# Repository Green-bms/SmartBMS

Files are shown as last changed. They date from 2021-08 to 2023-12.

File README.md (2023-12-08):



# SmartBMS
Open source Smart Battery Management System

Youtube presentation:
https://youtu.be/0XNe25lMs6U?si=eK-90N3kao_sy4zy

Official page:
https://hackaday.io/project/181453-green-bms

## Description
Smart BMS is an Open Source Battery Management System for Lithium Cells (Lifepo4, Li-ion, NCM, etc.) Battery Pack.



The main functions of BMS are:
- To protect cells against overvoltage
- To protect cells against undervoltage
- To balance the cells 

Smart BMS consists of four main components:
1. Cell Module (https://hackaday.io/project/181453-green-bms/log/198376-green-bms-cell-module)
2. Control Unit (https://hackaday.io/project/181453-green-bms/log/198414-green-bms-control-unit)
3. Limiter (https://hackaday.io/project/181453-green-bms/log/198378-green-bms-limiter)
4. Android App (https://hackaday.io/project/181453-green-bms/log/198377-green-bms-android-app)

The voltage and the temperature values of each cell are acquired by the relevant Cell Module (based on Attiny microcontroller) and sent to Control Unit (based on Arduino Mega microcontroller) through a serial I2C line.

Control Unit starts or stop charging (by output relay) through Limiter, that includes a power relay for opening or closing the charging circuit.

Control Unit can also start or stop discharging by output relay.

When during charging a cell reaches the “Balance voltage value parameter”, the Cell Module connects the balance resistors in order to perform the cell bleeding.

When just one cell of the pack is balancing, Control Unit activates the current limit function inside the Limiter (the charging current is limited to 1A).

Control Unit can be connected with a Smartphone (or a Tablet) by Bluetooth.

By “Green BMS” Android app (available on Play Store) it is possible to check the Battery Pack status (total voltage, current load, state of charge…) , to check the actual voltage and temperature values of each cell and to perform several settings.

## Android App free download
The Green BMS Android app is available here: 
[Green-BMS App](https://play.google.com/store/apps/details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)

## Tutorials

Step by step instructions for make Green BMS are available here:
https://hackaday.io/project/181453/instructions

## Youtube channel

https://www.youtube.com/channel/UCdJnQnmzJSQNOAGbZR5iExA

Subscribe please... :smile:

## Open source Development applications

The project was created using the following Open source applications:
- **KiCad** : to design cell module and Interface board
- **QElectroTech** : to design Limiter
- **LibreCad 2D** : to desingn Control Unit Box
- **Arduino IDE** : to design the code of Cell Module(Attiny) and Control Unit(Arduino Mega)
- **Mit App Inventor** : to design the Android Application

## Warning

Lithium and other batteries are dangerous and must be treated with care.

Lithium and other batteries are potentially hazardous and can present a serious fire hazard if damaged, defective or improperly used.

Green BMS is a "do it yourself" project, with no warranties whatsoever.

Green BMS assumes no responsibility for any errors or inaccuracies that may appear in any documentation or file or any software that may be provided.

The use of this project is done entirely at your own risk and responsibility.

The use of this project may not be compliant with local laws or regulations.

## Open Source Hardware Certification

Green BMS has been certified as open source hardware by the Open Source Hardware Association, with the UID: IT000007.

Certificate link: (https://certification.oshwa.org/it000007.html)

## License

This work is licensed under a **Creative Commons Attribution-ShareAlike 4.0 International License**.
https://creativecommons.org/licenses/by-sa/4.0/

### You are free to:

**Share** — copy and redistribute the material in any medium or format

**Adapt**  — remix, transform, and build upon the material
for any purpose, even commercially.
This license is acceptable for Free Cultural Works.
The licensor cannot revoke these freedoms as long as you follow the license terms.

### Under the following terms:

**Attribution** — You must give appropriate credit, provide a link to the license, and indicate if changes were made. You may do so in any reasonable manner, but not in any way that suggests the licensor endorses you or your use.

**ShareAlike** — If you remix, transform, or build upon the material, you must distribute your contributions under the same license as the original.

**No additional restrictions** — You may not apply legal terms or technological measures that legally restrict others from doing anything the license permits.

### Notices:
You do not have to comply with the license for elements of the material in the public domain or where your use is permitted by an applicable exception or limitation.
No warranties are given. The license may not give you all of the permissions necessary for your intended use. For example, other rights such as publicity, privacy, or moral rights may limit how you use the material.

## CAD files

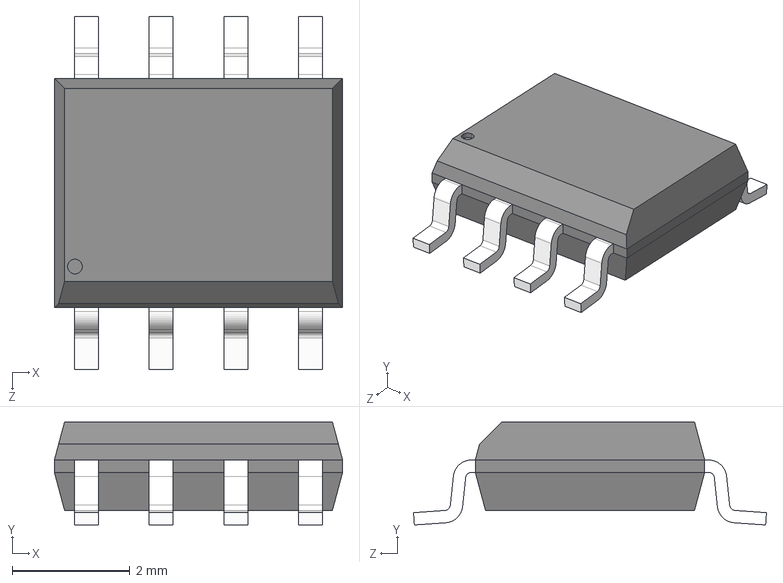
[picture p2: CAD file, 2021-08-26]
01_Documentation/Kikad additional libreries/Adum1250/ADUM1250.step
4.90 x 1.75 x 6.00 mm

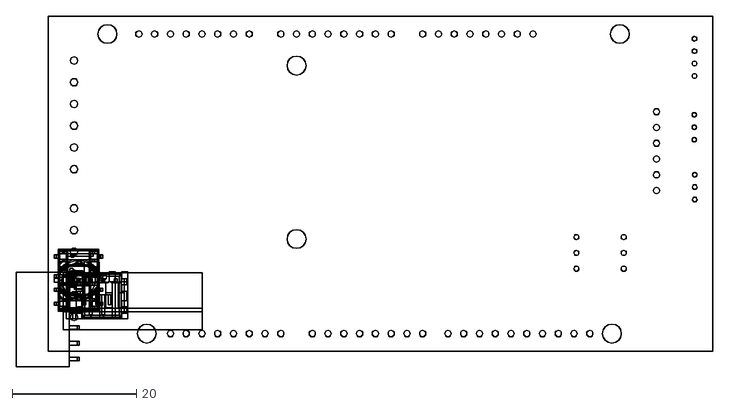
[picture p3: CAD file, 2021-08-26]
04_Interface board/Hardware/Kikad_Interface_board_1/Interface_board_1.dxf
112.2 x 56.5

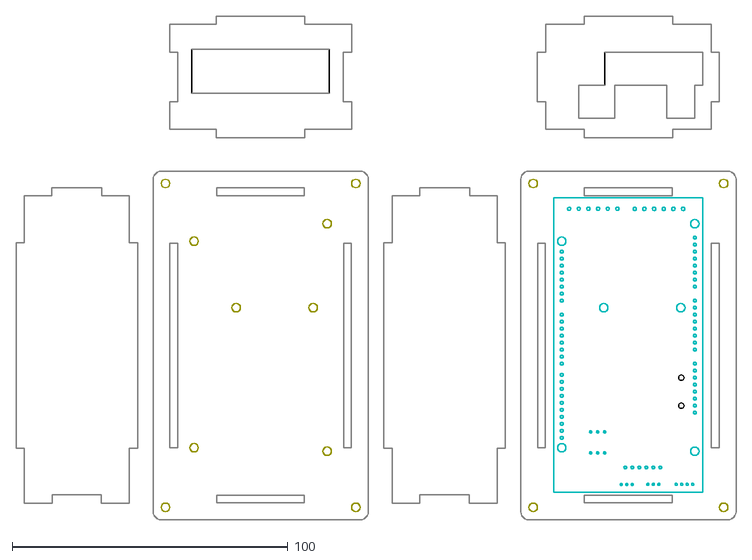
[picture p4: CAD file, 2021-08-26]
05_Control Unit case/Librecad_box_lcu_0_0/box_lcu_0_0.dxf
261.2 x 182.7

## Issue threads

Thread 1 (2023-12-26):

Implement taper current charging

idkq, 2023-12-26:
To implement taper current charging, the code would need to integrate real-time monitoring of the battery’s state of charge (SOC) and adjust the charging current accordingly as the SOC approaches 100%.

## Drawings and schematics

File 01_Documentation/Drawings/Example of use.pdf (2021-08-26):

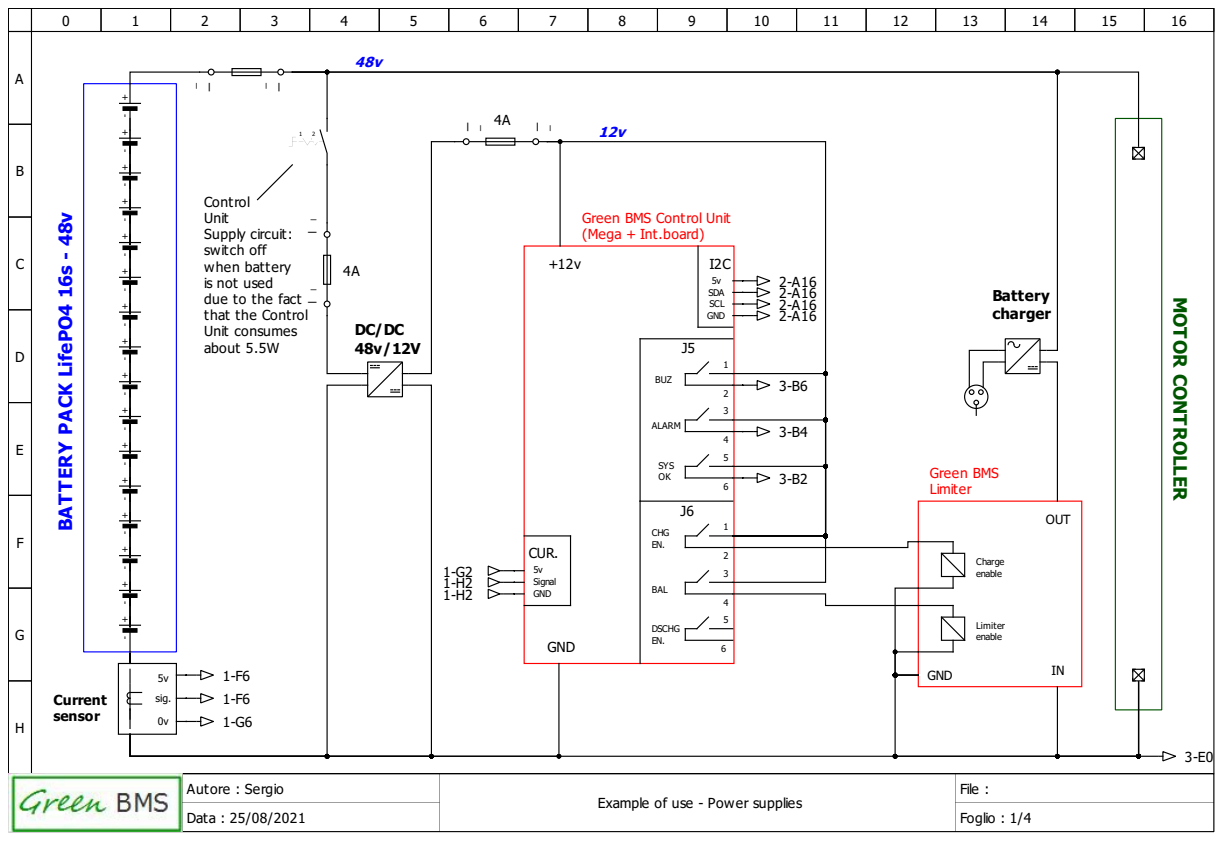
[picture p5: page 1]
ABCDEFGH; gio; ple; plie; File : Data : 25/08/2021; Foglio : 1; Limit; ble; 1 SDA5v SCL GND I2C J6 BAL CHG EN. CUR. Signal; Green BMS Control Unit (Mega + Int.board); 3253 GND 5v; BUZ J5 SYS OK DSCHG EN. ALARM; 4 GND; 0v sig. 5v ⁻ ⁺ ⁻ ⁺ ⁻ ⁺; MOTOR CONTROLLER; BATTERY PACK LifePO4 16s - 48v; ol Unit Supply; cir c

uit: switch off when battery is not used due to the fac

ol Unit consumes about 5.5W

16 | 15 | 14 | 13

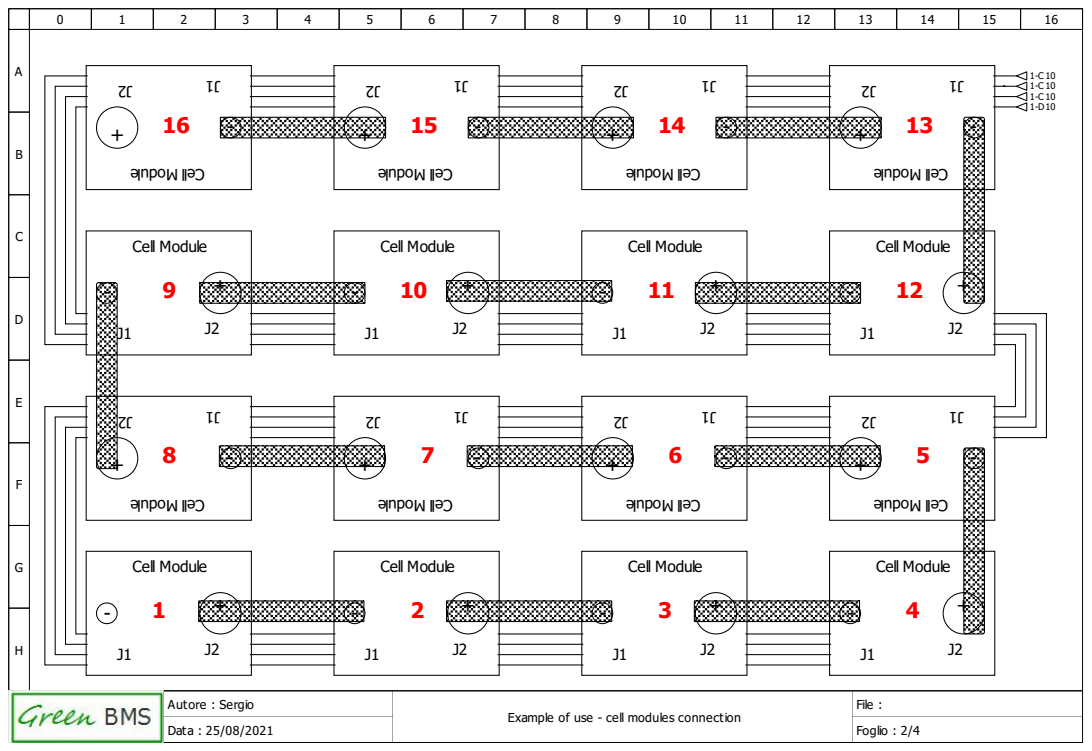
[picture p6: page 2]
Cell Module

Autore : Sergio | Example of use - cell modules connection | File :

Data : 25/08/2021 | | Foglio : 2/4

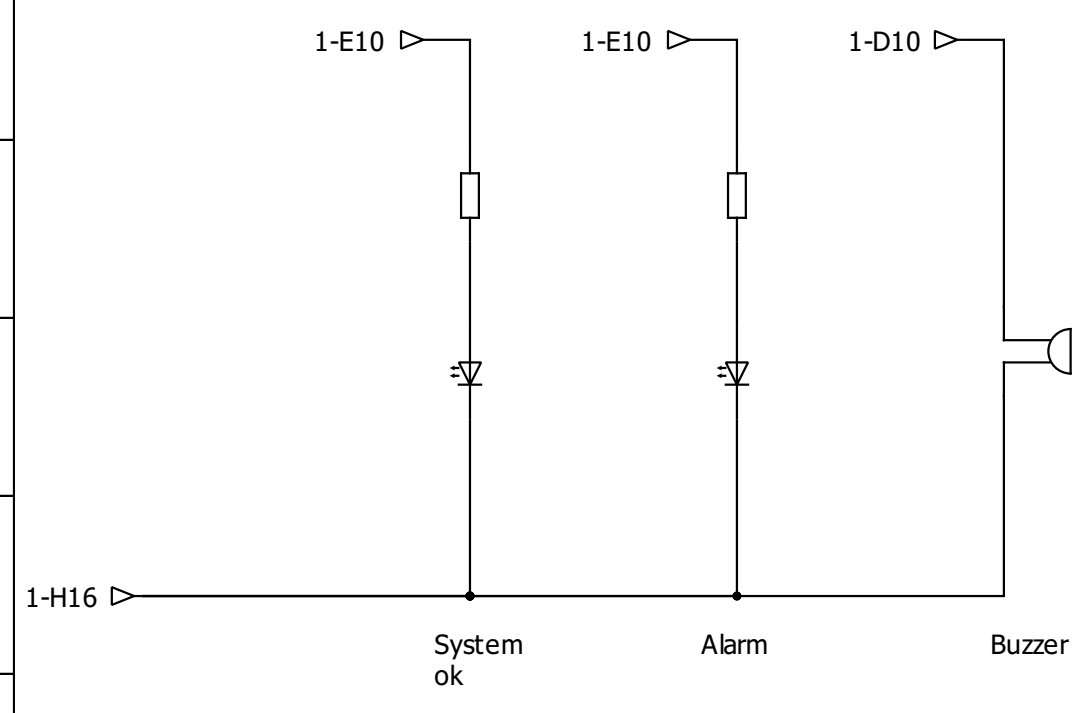
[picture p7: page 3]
Autore : Sergio; File :; System ok; Alarm; Buzzer

Example of use - indications

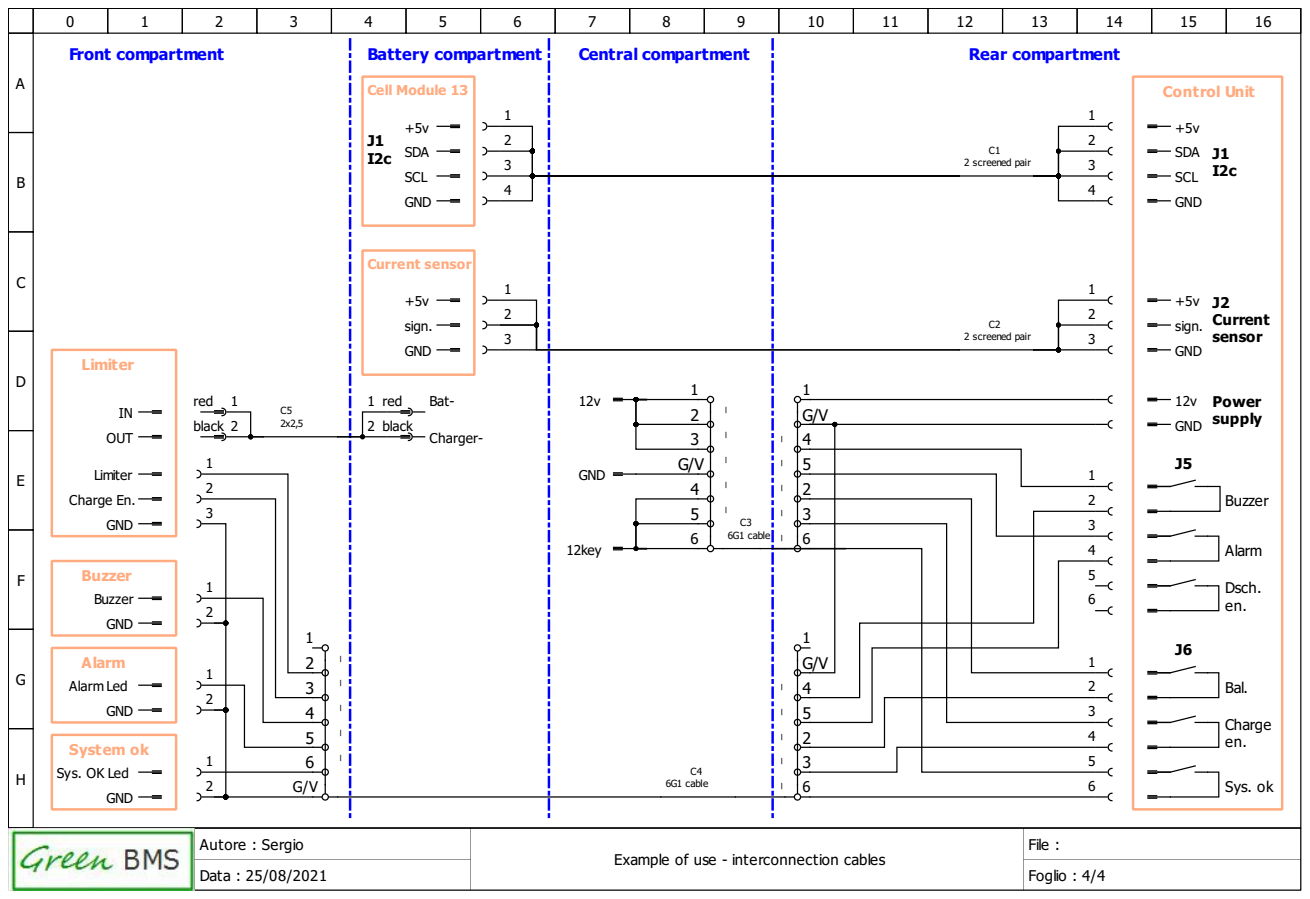
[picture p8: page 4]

Example of use - interconnection cables

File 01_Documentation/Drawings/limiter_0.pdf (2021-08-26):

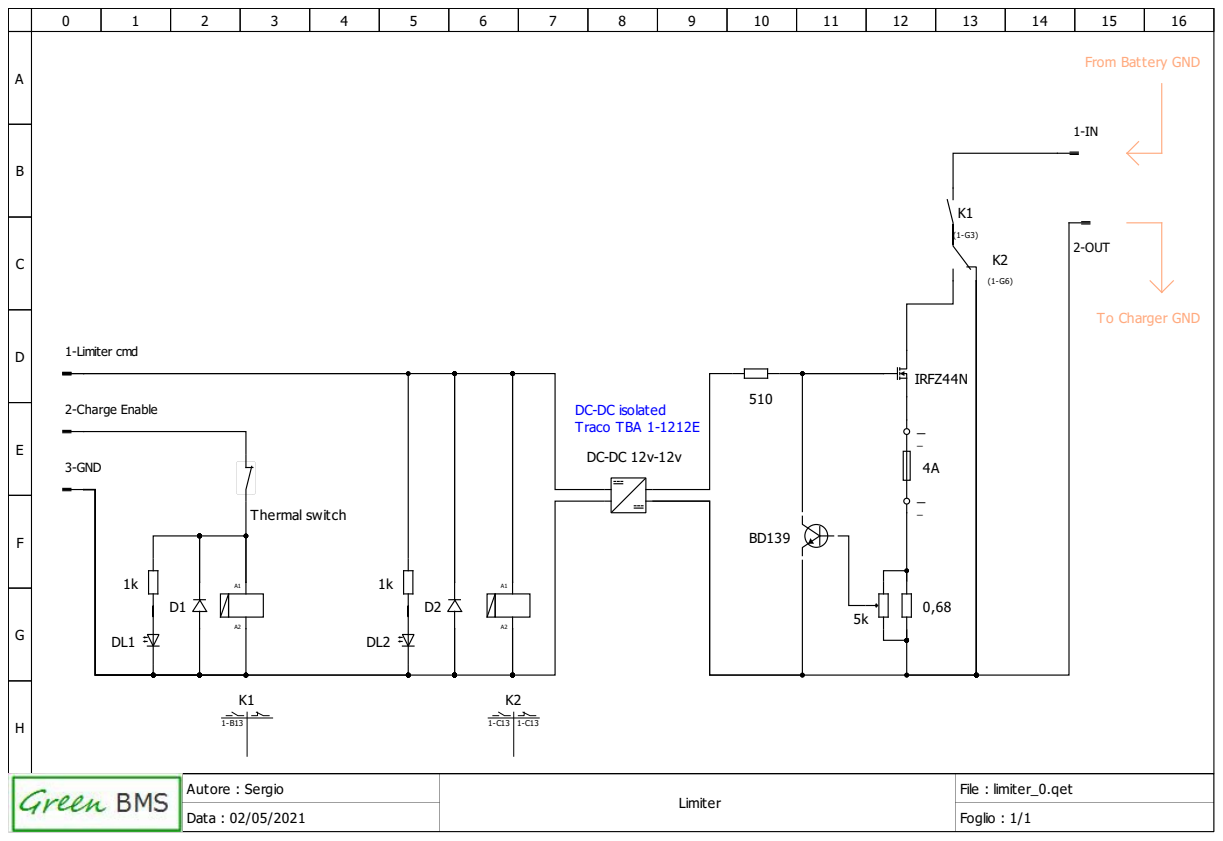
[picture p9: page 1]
1-Limiter cmd; IRFZ44N; Thermal switch; 3-GND; 2-Charge Enable; 2-OUT

From Battery GND

To Charger GND

DC-DC isolated
Traco TBA 1-1212E

Autore : Sergio | Limiter | File : limiter_0.qet

Data : 02/05/2021 | | Foglio : 1/1

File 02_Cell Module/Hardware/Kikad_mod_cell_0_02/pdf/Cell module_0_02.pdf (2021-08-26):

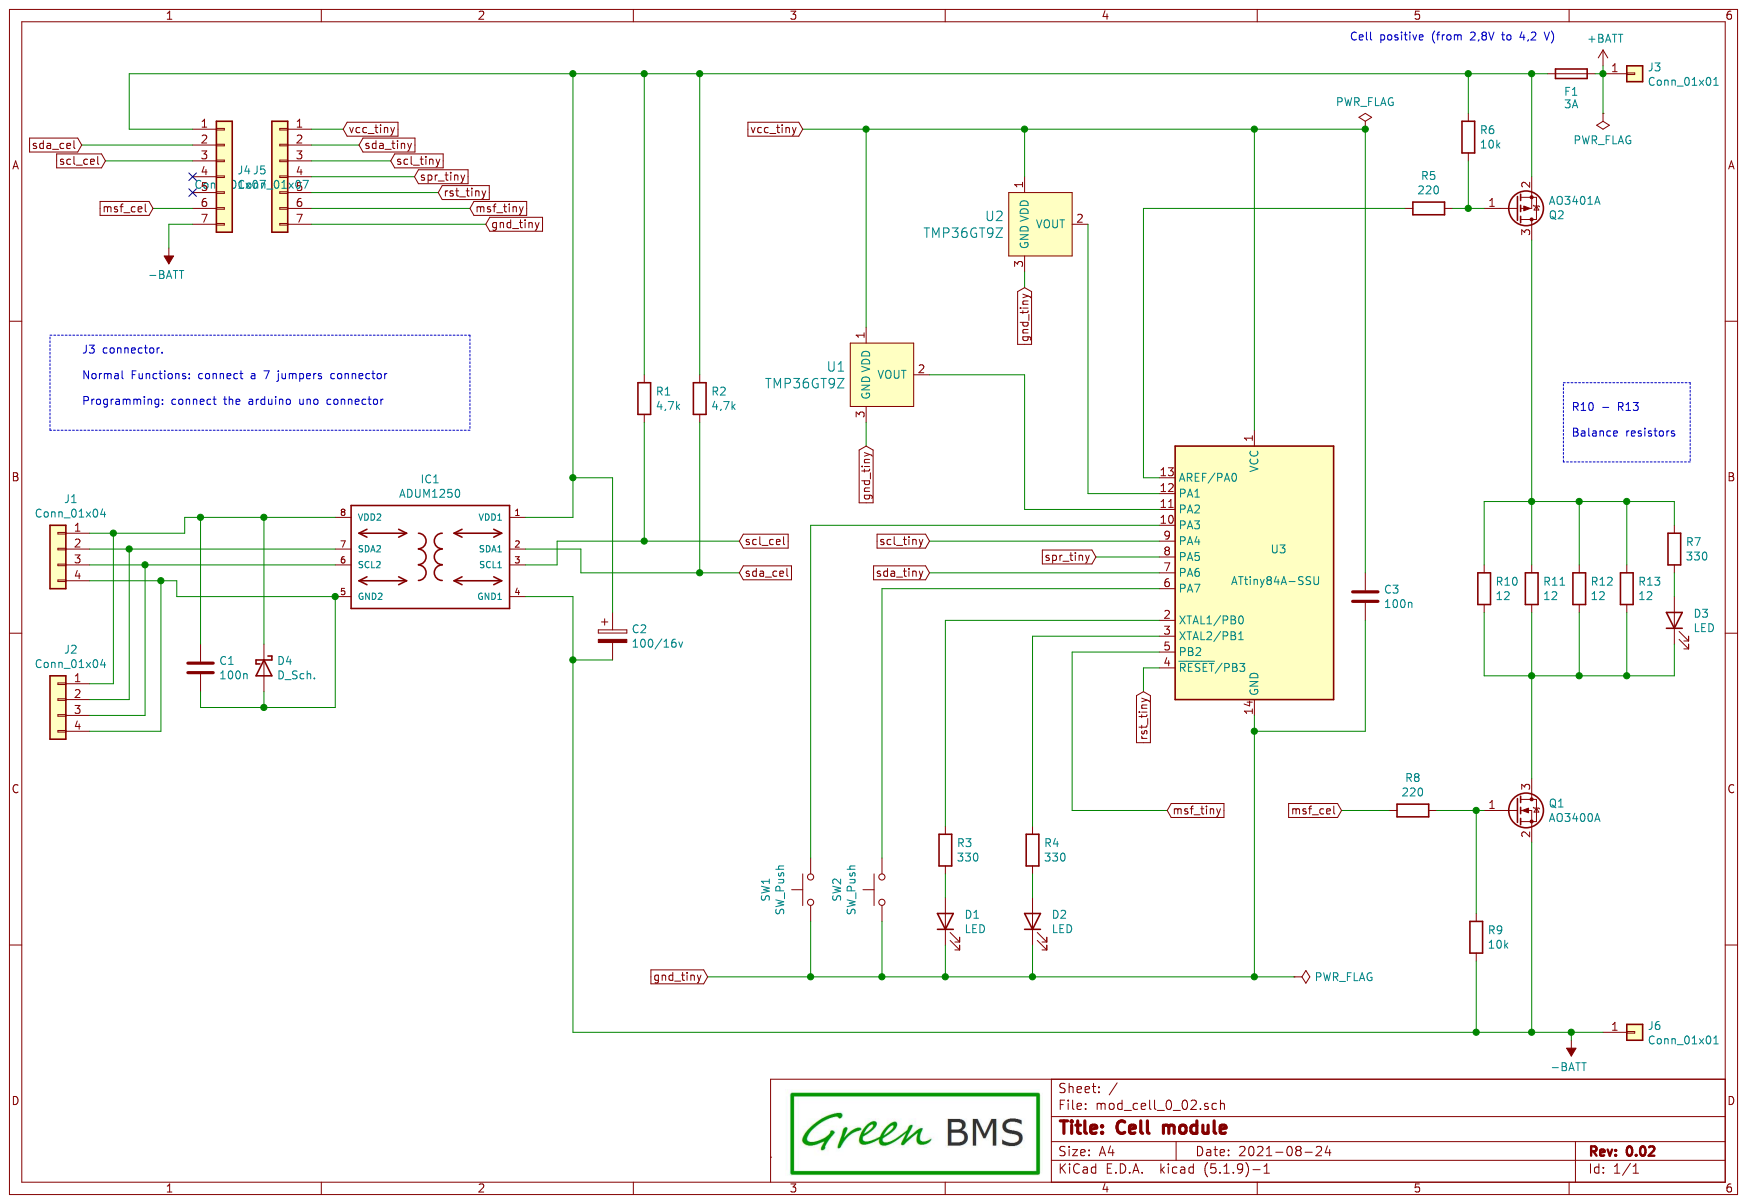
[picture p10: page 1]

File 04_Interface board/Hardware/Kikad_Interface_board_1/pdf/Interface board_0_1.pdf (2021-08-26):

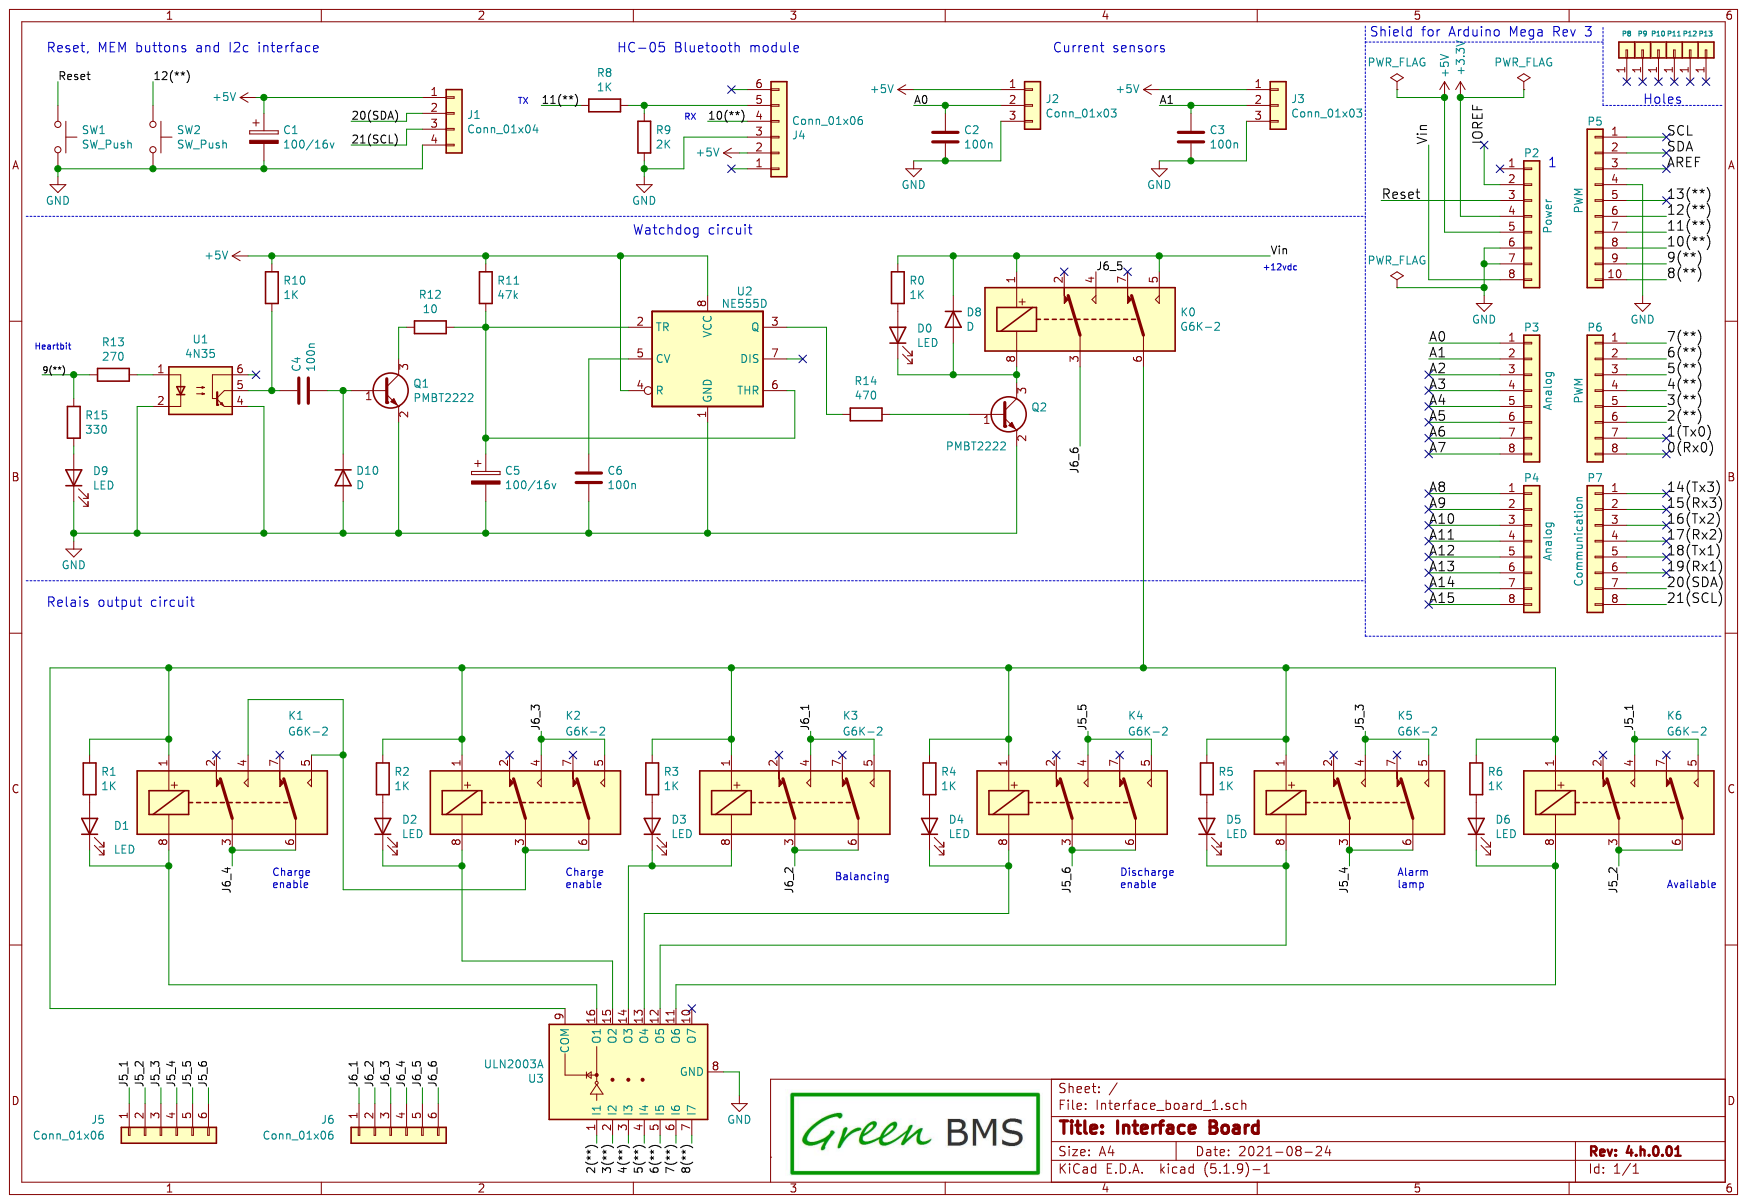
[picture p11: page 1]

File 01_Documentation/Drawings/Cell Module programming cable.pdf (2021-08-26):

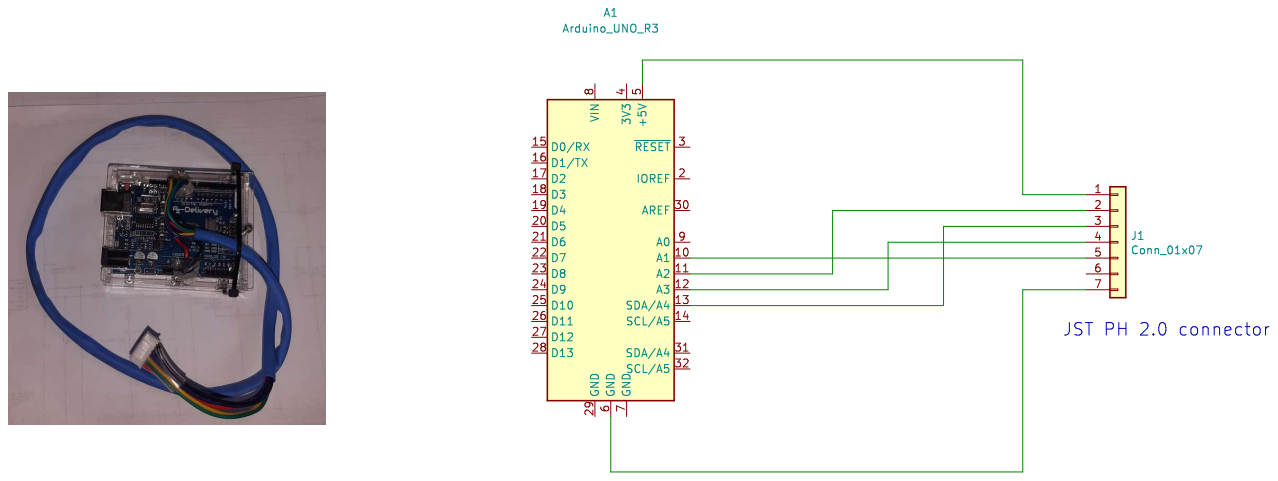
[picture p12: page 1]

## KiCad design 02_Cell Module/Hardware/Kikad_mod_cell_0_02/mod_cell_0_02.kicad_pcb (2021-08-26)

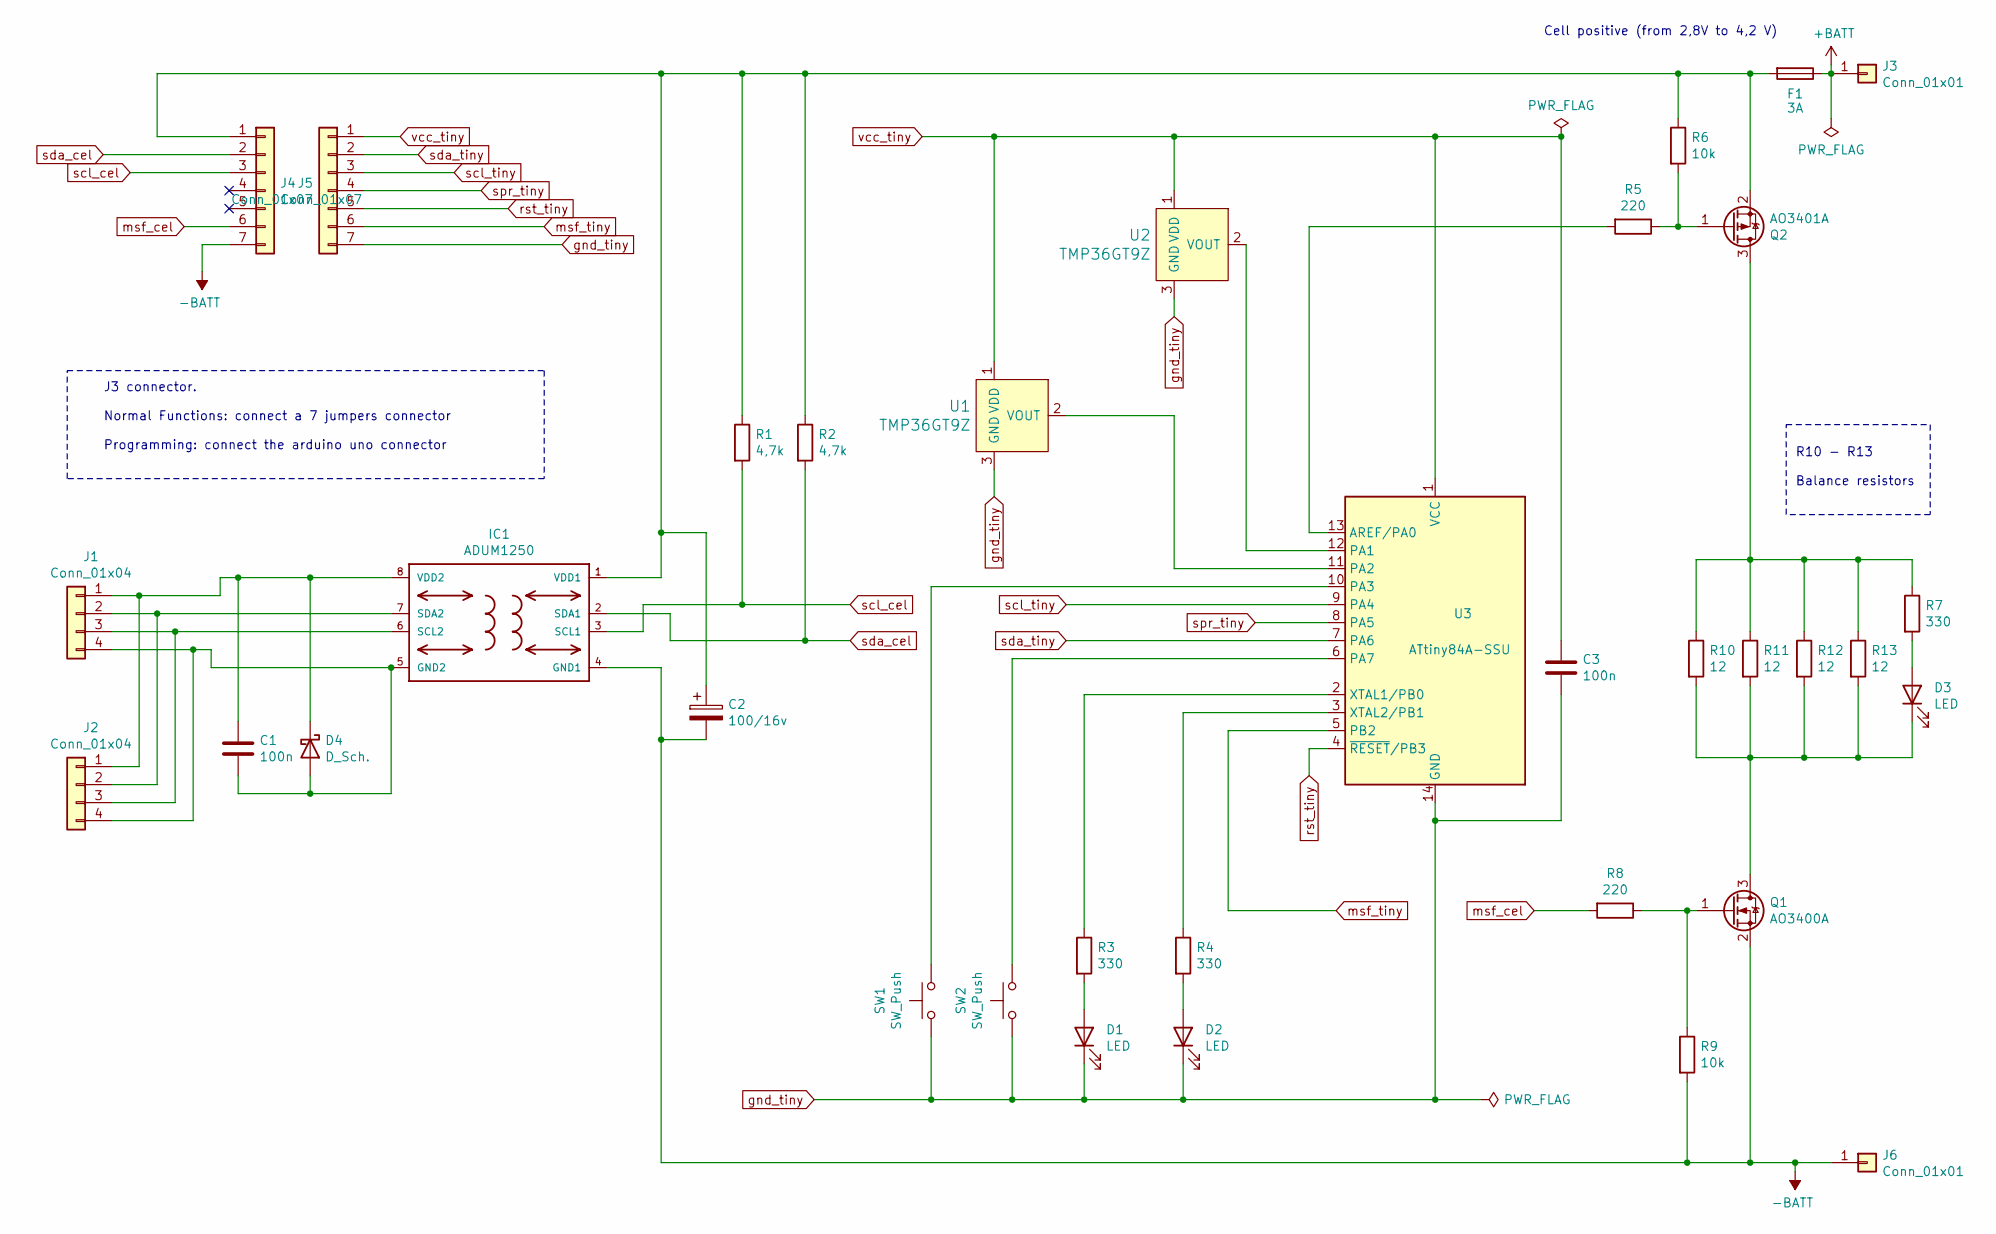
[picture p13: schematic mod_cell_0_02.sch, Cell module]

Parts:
C1, C3: 100n; C_1206_3216Metric
C2: 100/16v; CP_Elec_6.3x5.8
D1, D2, D3: LED; LED_1206_3216Metric
D4: D_Sch.; D_SMA
F1: 3A; Fuse_1206_3216Metric
IC1: ADUM1250; SOIC-8_3.9x4.9mm_P1.27mm
J1, J2: Conn_01x04; JST_PH_B4B-PH-K_1x04_P2.00mm_Vertical
J3: Conn_01x01; SolderWire-battery_cell_pole_2
J4, J5: Conn_01x07; JST_PH_B7B-PH-K_1x07_P2.00mm_Vertical
J6: Conn_01x01; SolderWire-battery_cell_for_wire_2
Q1: AO3400A; SOT-23
Q2: AO3401A; SOT-23
R1, R2: 4,7k; R_1206_3216Metric
R3, R4, R7: 330; R_1206_3216Metric
R5, R8: 220; R_1206_3216Metric
R6, R9: 10k; R_1206_3216Metric
R10, R11, R12, R13: 12; R_Axial_DIN0922_L20.0mm_D9.0mm_P25.40mm_Horizontal
SW1, SW2: SW_Push; SW_Push_SPST_NO_Alps_SKRK
U1, U2: TMP36GT9Z; TO-92-3; MPN TMP36GT9Z; Digi-Key_PN TMP36GT9Z-ND
U3: ATtiny84A-SSU; SOIC-14_3.9x8.7mm_P1.27mm

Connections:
+BATT: F1.1, J3.1
-BATT: C2.2, IC1.4 (GND1), J4.7, J6.1, Q1.2 (S), R9.2
unnamed: C1.1, D4.1 (K), IC1.8 (VDD2), J1.1, J2.1
unnamed: C1.2, D4.2 (A), IC1.5 (GND2), J1.4, J2.4
unnamed: C2.1, F1.2, IC1.1 (VDD1), J4.1, Q2.2 (S), R1.1, R2.1, R6.1
unnamed: D1.2 (A), R3.2
unnamed: D2.2 (A), R4.2
unnamed: D3.1 (K), Q1.3 (D), R10.2, R11.2, R12.2, R13.2
unnamed: D3.2 (A), R7.2
unnamed: IC1.6 (SCL2), J1.3, J2.3
unnamed: IC1.7 (SDA2), J1.2, J2.2
unnamed: Q1.1 (G), R8.1, R9.1
unnamed: Q2.1 (G), R5.1, R6.2
unnamed: Q2.3 (D), R7.1, R10.1, R11.1, R12.1, R13.1
unnamed: R3.1, U3.2 (XTAL1/PB0)
unnamed: R4.1, U3.3 (XTAL2/PB1)
unnamed: R5.2, U3.13 (AREF/PA0)
unnamed: SW1.2, U3.10 (PA3)
unnamed: SW2.2, U3.6 (PA7)
unnamed: U1.2 (VOUT), U3.11 (PA2)
unnamed: U2.2 (VOUT), U3.12 (PA1)
gnd_tiny: C3.2, D1.1 (K), D2.1 (K), J5.7, SW1.1, SW2.1, U1.3 (GND), U2.3 (GND), U3.14 (GND)
msf_cel: J4.6, R8.2
msf_tiny: J5.6, U3.5 (PB2)
rst_tiny: J5.5, U3.4 (~RESET~/PB3)
scl_cel: IC1.3 (SCL1), J4.3, R1.2
scl_tiny: J5.3, U3.9 (PA4)
sda_cel: IC1.2 (SDA1), J4.2, R2.2
sda_tiny: J5.2, U3.7 (PA6)
spr_tiny: J5.4, U3.8 (PA5)
vcc_tiny: C3.1, J5.1, U1.1 (VDD), U2.1 (VDD), U3.1 (VCC)

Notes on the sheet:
Cell positive (from 2,8V to 4,2 V)
J3 connector. Normal Functions: connect a 7 jumpers connector Programming: connect the arduino uno connector
R10 - R13 Balance resistors

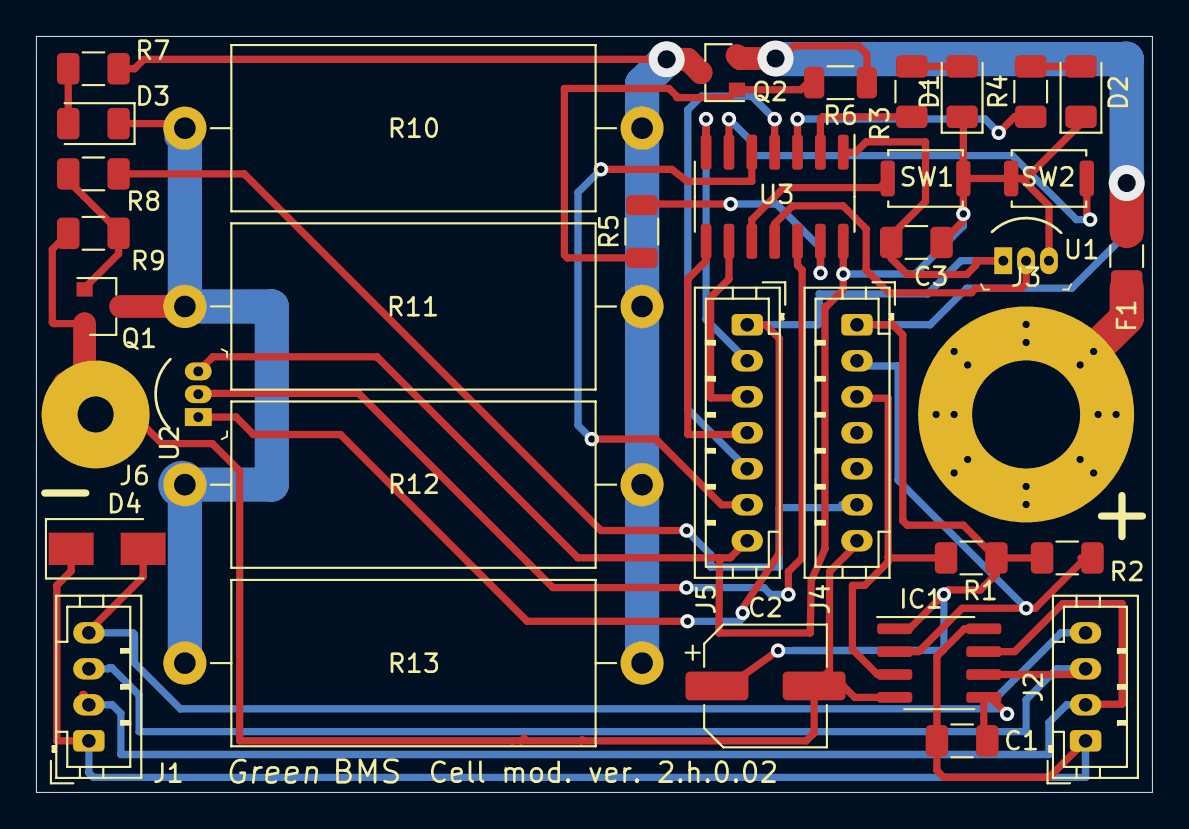
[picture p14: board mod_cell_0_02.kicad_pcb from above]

Board: 2 copper layers, 62.0 x 42.0 mm, 35 parts (0 on the bottom side), 31 nets.

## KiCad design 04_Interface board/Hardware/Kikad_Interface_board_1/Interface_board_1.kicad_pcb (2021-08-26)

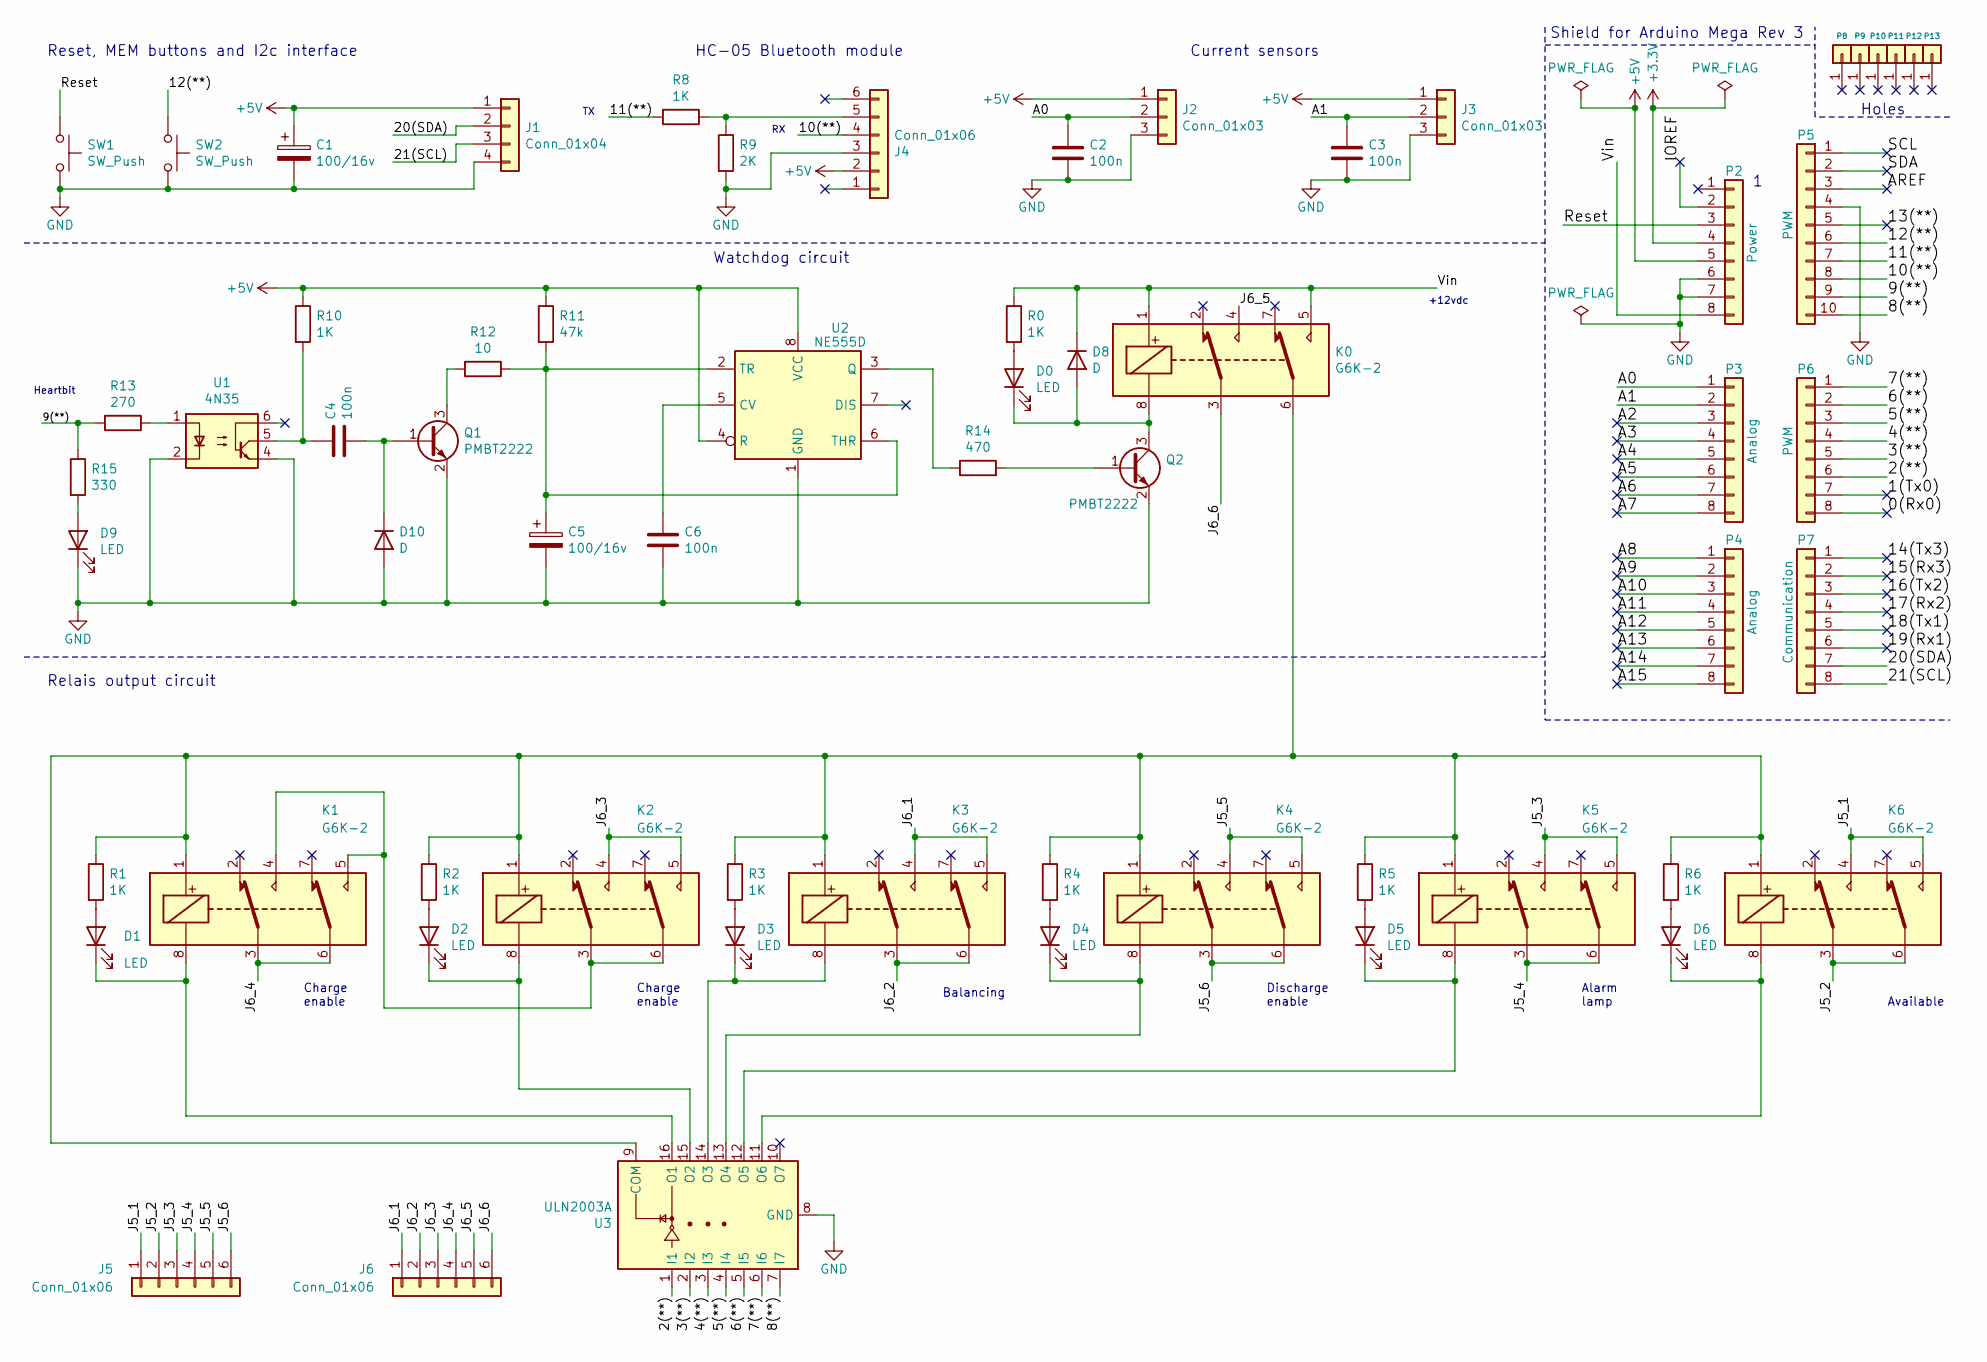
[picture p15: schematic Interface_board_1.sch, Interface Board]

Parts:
C1, C5: 100/16v; CP_Elec_6.3x5.8
C2, C3, C4, C6: 100n; C_1206_3216Metric
D0, D1, D2, D3, D4, D5, D6, D9: LED; LED_1206_3216Metric
D8, D10: D; D_1206_3216Metric
J1: Conn_01x04; JST_PH_S4B-PH-K_1x04_P2.00mm_Horizontal
J2, J3: Conn_01x03; JST_PH_S3B-PH-K_1x03_P2.00mm_Horizontal
J4: Conn_01x06; PinSocket_1x06_P2.54mm_Horizontal
J5, J6: Conn_01x06; PhoenixContact_MC_1,5_6-G-3.5_1x06_P3.50mm_Horizontal
K0, K1, K2, K3, K4, K5, K6: G6K-2; Relay_DPDT_Omron_G6K-2F-Y
P2: Power; Socket_Strip_Arduino_1x08
P3, P4: Analog; Socket_Strip_Arduino_1x08
P5: PWM; Socket_Strip_Arduino_1x10
P6: PWM; Socket_Strip_Arduino_1x08
P7: Communication; Socket_Strip_Arduino_1x08
P8, P9, P10, P11, P12, P13: CONN_01X01; Arduino_1pin
Q1, Q2: PMBT2222; SOT-23
R0, R1, R2, R3, R4, R5, R6, R8, R10: 1K; R_1206_3216Metric
R9: 2K; R_1206_3216Metric
R11: 47k; R_1206_3216Metric
R12: 10; R_1206_3216Metric
R13: 270; R_1206_3216Metric
R14: 470; R_1206_3216Metric
R15: 330; R_1206_3216Metric
SW1, SW2: SW_Push; SW_Push_SPST_NO_Alps_SKRK
U1: 4N35; DIP-6_W7.62mm
U2: NE555D; SOIC-8_3.9x4.9mm_P1.27mm
U3: ULN2003A; SOIC-16_3.9x9.9mm_P1.27mm

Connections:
+3V3: P2.4
+5V: C1.1, J1.1, J2.1, J3.1, J4.2, P2.5, R10.1, R11.1, U2.4 (R), U2.8 (VCC)
/0(Rx0): P6.8
/1(Tx0): P6.7
/2(**): P6.6, U3.1 (I1)
/3(**): P6.5, U3.2 (I2)
/4(**): P6.4, U3.3 (I3)
/5(**): P6.3, U3.4 (I4)
/6(**): P6.2, U3.5 (I5)
/7(**): P6.1, U3.6 (I6)
/8(**): P5.10, U3.7 (I7)
/9(**): P5.9, R13.2, R15.1
/10(**): J4.4, P5.8
/11(**): P5.7, R8.2
/12(**): P5.6, SW2.1
/13(**): P5.5
/14(Tx3): P7.1
/15(Rx3): P7.2
/16(Tx2): P7.3
/17(Rx2): P7.4
/18(Tx1): P7.5
/19(Rx1): P7.6
/20(SDA): J1.2, P7.7
/21(SCL): J1.3, P7.8
/A0: C2.1, J2.2, P3.1
/A1: C3.1, J3.2, P3.2
/A2: P3.3
/A3: P3.4
/A4: P3.5
/A5: P3.6
/A6: P3.7
/A7: P3.8
/A8: P4.1
/A9: P4.2
/A10: P4.3
/A11: P4.4
/A12: P4.5
/A13: P4.6
/A14: P4.7
/A15: P4.8
/AREF: P5.3
/IOREF: P2.2
/J5_1: J5.1, K6.4, K6.5
/J5_2: J5.2, K6.3, K6.6
/J5_3: J5.3, K5.4, K5.5
/J5_4: J5.4, K5.3, K5.6
/J5_5: J5.5, K4.4, K4.5
/J5_6: J5.6, K4.3, K4.6
/J6_1: J6.1, K3.4, K3.5
/J6_2: J6.2, K3.3, K3.6
/J6_3: J6.3, K2.4, K2.5
/J6_4: J6.4, K1.3, K1.6
/J6_5: J6.5, K0.4
/J6_6: J6.6, K0.3
/Reset: P2.3, SW1.1
/SCL: P5.1
/SDA: P5.2
/Vin: D8.1 (K), K0.1, K0.5, P2.8, R0.1
GND: C1.2, C2.2, C3.2, C5.2, C6.2, D9.1 (K), D10.2 (A), J1.4, J2.3, J3.3, J4.3, P2.6, P2.7, P5.4, Q1.2 (E), Q2.2 (E), R9.2, SW1.2, SW2.2, U1.2, U1.4, U2.1 (GND), U3.8 (GND)
unnamed: C4.1, R10.2, U1.5
unnamed: C4.2, D10.1 (K), Q1.1 (B)
unnamed: C5.1, R11.2, R12.1, U2.2 (TR), U2.6 (THR)
unnamed: C6.1, U2.5 (CV)
unnamed: D0.1 (K), D8.2 (A), K0.8, Q2.3 (C)
unnamed: D0.2 (A), R0.2
unnamed: D1.1 (K), K1.8, U3.16 (O1)
unnamed: D1.2 (A), R1.2
unnamed: D2.1 (K), K2.8, U3.15 (O2)
unnamed: D2.2 (A), R2.2
unnamed: D3.1 (K), K3.8, U3.14 (O3)
unnamed: D3.2 (A), R3.2
unnamed: D4.1 (K), K4.8, U3.13 (O4)
unnamed: D4.2 (A), R4.2
unnamed: D5.1 (K), K5.8, U3.12 (O5)
unnamed: D5.2 (A), R5.2
unnamed: D6.1 (K), K6.8, U3.11 (O6)
unnamed: D6.2 (A), R6.2
unnamed: D9.2 (A), R15.2
unnamed: J4.5, R8.1, R9.1
unnamed: K0.6, K1.1, K2.1, K3.1, K4.1, K5.1, K6.1, R1.1, R2.1, R3.1, R4.1, R5.1, R6.1, U3.9 (COM)
unnamed: K1.4, K1.5, K2.3, K2.6
unnamed: Q1.3 (C), R12.2
unnamed: Q2.1 (B), R14.2
unnamed: R13.1, U1.1
unnamed: R14.1, U2.3 (Q)

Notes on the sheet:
Holes
Shield for Arduino Mega Rev 3
Reset, MEM buttons and I2c interface
Current sensors
HC-05 Bluetooth module
Heartbit
Watchdog circuit
+12vdc
Charge enable
Discharge enable
Balancing
Alarm lamp
Available
Relais output circuit

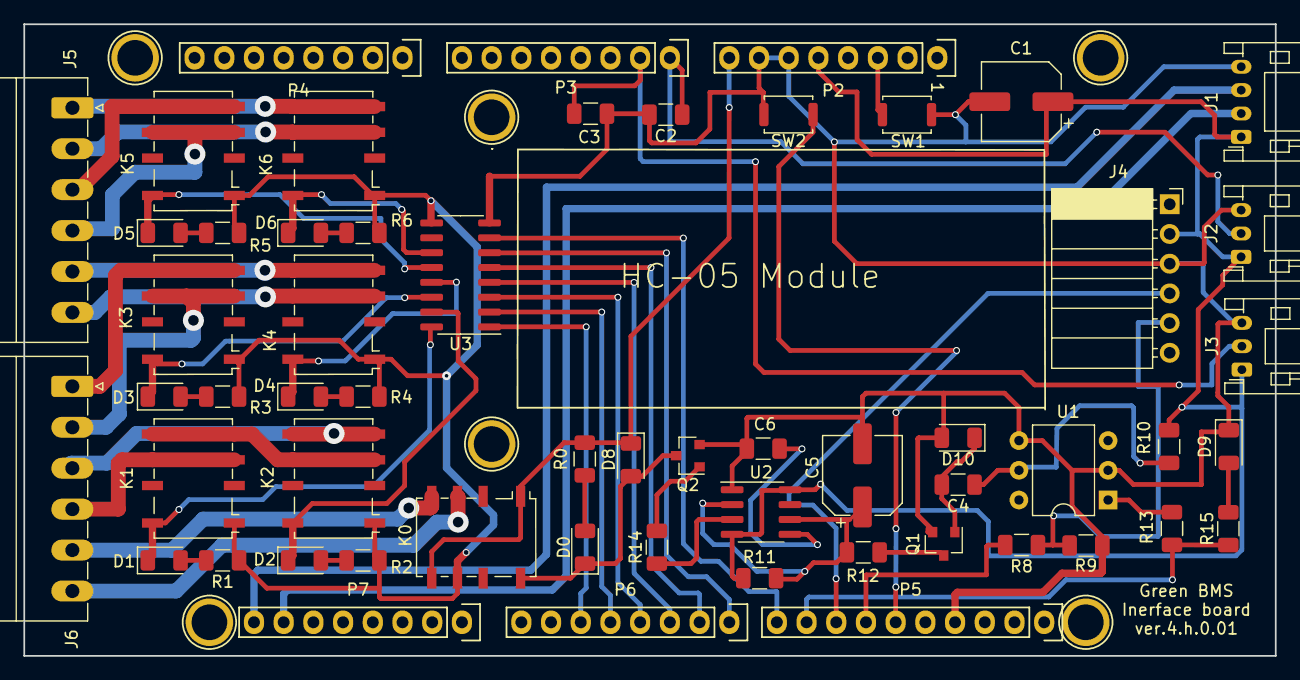
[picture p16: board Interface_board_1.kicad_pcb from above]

Board: 2 copper layers, 107.0 x 54.0 mm, 63 parts (0 on the bottom side), 57 nets.

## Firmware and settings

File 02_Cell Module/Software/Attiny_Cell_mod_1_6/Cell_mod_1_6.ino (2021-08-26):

/*
  Cell_mod
  
  Single Lithium Battery Cell module management included in Green BMS project.
  Cell module is based on Attiny 84 controller supplied by the cell and programmed with Arduino UNO (Arduino as isp).
  Cell module functions are:
    - To communicate by I2c with the Master Unit called "Control Unit"
    - To send to Control Unit the values of: cell voltage, cell pole temperature, balancing resistor temperature for battery pack management system
    - To execute the cell balancing (by a mosfet) according to Control Unit command, 
  Each cell module I2C address can be programmed by the user, by push buttons, checking tens and units values by the blinking of two leds
  It is possible to set address from 1 to 99. Address is stored on Attiny EEPROM.
  Cell module sketch includes safety conditions that stop balancing command and reset the program in case of:
    - Internal Whatchdog error (reset after 8 sec.)
    - Loss of I2C Communication with Control Unit (reset after 20 sec.)

  Versions:

  - Ver. 2.s.1.06 date 03/06/2021 created by Sergio Ghirardelli (first release)
  
  
   
*/

#include <TinyWireS.h>
#include <EEPROM.h>
#include "functions_4.h"
#include <avr/wdt.h> 

/*Variable declaration. Meaning of each varable is indicated on instructions comments */
unsigned long t, sample, t0, t1;

unsigned long u_elapsed, u_count, da_elapsed, da_count;
unsigned long both_elapsed, both_count;
unsigned long net_elapsed, net_count;
bool osc, but_u, but_da, u, da, both, both_p, both_mem, prog, prog_p, prog_mem, prog_n, prog_mem2, osc_n, osc_mem;
bool u_n, u_mem, da_n, da_mem;
int u_number, da_number, new_address, u_led_preset, u_led_elapsed, da_led_preset, da_led_elapsed, address, gain_offset;
float val_diff, val_gain;

int temp1_input, temp1_index, temp1_mem[10], temp1_mv, temp1_filtered;
int temp2_input, temp2_index, temp2_mem[10], temp2_mv, temp2_filtered;
long volt, volt_index, volt_mem[10], volt_filtered, vx;
long vbal, vbal_index, vbal_mem[10];

long input, index, val_mem[10], val;
float rbal, rfuse;
unsigned long t_life;
bool check, ardu_test, ardu_bleed, ardu_rst, net_fault, comp_enable, bleed_on;
byte temp1, temp2, tiny_life, ardu_life, ardu_bal, ardu_cmd, life_mem, tiny_bal;

/*balance oscillator variables*/
unsigned long elapsed_time1;
unsigned long count_time1; 
bool time1_q;
unsigned long elapsed_time2;
unsigned long count_time2; 
bool time2_q;
unsigned long elapsed_time3;
unsigned long count_time3; 
bool time3_q;


void(* Riavvia)(void) = 0; //Sketch Reset procedure

void setup() {
  wdt_disable(); //watchdog dog check diseable
  
  /*Set of starting values*/
  sample = 0;
  u = 0;
  da = 0;
  u_number = 0;
  da_number = 0;
  prog = false;
  tiny_bal = 0;
  rbal = 3000.0; //balance resistor in milli-ohm
  rfuse = 48; // fuse resistence causing voltage drop during balancing
  time1_q = false;
  time2_q = false;
  time3_q = false;
  bleed_on = false;

  /*I/O pins configuration  */
  pinMode(10, OUTPUT);
  pinMode(9, OUTPUT);
  pinMode(8, OUTPUT);
  pinMode(0, OUTPUT);
  pinMode(3, INPUT_PULLUP);
  pinMode(7, INPUT_PULLUP);
  
  address = EEPROM.read(0); //module I2C address reading from EEPROM
  EEPROM.get (2,gain_offset);
  new_address = address;
  
  TinyWireS.begin(address); // join i2c network
  TinyWireS.onRequest(requestEvent);
  TinyWireS.onReceive(receiveEvent);
  
  digitalWrite(9, LOW); //leds lights on for 2 seconds to show the sketch reset 
  digitalWrite(10, LOW);
  
  wdt_enable(WDTO_8S); //watchdog enabled and set to 8 seconds
  delay(2000);
}


void loop() {

/*Push buttons managements*/
  but_u = !digitalRead(3); //digital channels reading
  but_da = !digitalRead(7);
  u = TON(but_u, 50, u_elapsed, u_count); //buttons must be pressed for at least 50 msec
  da = TON(but_da, 50, da_elapsed, da_count);
  both = TON ((u and da), 3000, both_elapsed, both_count);//both buttons are pressed for 3 seconds
  both_p = PosTrig(both, both_mem); //positive edge of both variable
  prog_p = PosTrig(prog, prog_mem); //positive edge of prog: when program mode is set
  prog_n = NegTrig(prog, prog_mem2); //negative edge of prog: when program mode is reset
  u_n = NegTrig(u, u_mem); //negative edge of u: when SW1 button is released
  da_n = NegTrig (da, da_mem); //negative edge of da: when SW2 button is released

/*Program mode or Normal mode calling*/
  if (prog) {
    program();
  }

  else {
    normal();
  }

/*I2C and watchdog reset*/
  TinyWireS_stop_check();
  wdt_reset();
}


/*Normal mode of cell module working*/
void normal() {

  if (prog_n) { // executed one time at the end of program mode 
    sample = 20; // voltage and temperatures reading sample time (in msec)
    digitalWrite(9, HIGH); // both leds on to show the end of program mode
    digitalWrite(10, HIGH);
    address = new_address; // I2C address takes the programmed value
    EEPROM.write(0, address); // I2C address is written to Attiny EEPROM
    TinyWireS.begin(address); // join i2c network
    TinyWireS.onRequest(requestEvent);
    TinyWireS.onReceive(receiveEvent);
    delay(3000); //three seconds of freezing before starting the normal mode
  }

  prog = both_p; //in case of pressing of both buttons for 3 seconds, system moves to program mode


  if (millis() - t >= sample) // executed one time every sample time
  {
    /*Attiny supply voltage reading and filtering*/
    input = readVcc();
    val = FILTER_LONG (input, index, val_mem);
 
    
    /*Temperature sensor 1  reading and filtering*/
    temp1_input = analogRead(A1);
    temp1_filtered = FILTER_INT (temp1_input, temp1_index, temp1_mem);

    /*Temperature sensor 1  reading and filtering*/
    temp2_input = analogRead(A2);
    temp2_filtered = FILTER_INT (temp2_input, temp2_index, temp2_mem);
  
    t += sample;

  }

  if (millis() - t1 >= 100) // executed one time every 100 msec
  {
    osc = !osc; //this creates a square wave with a period of 200 msec
    tiny_life++; //increment of sign of life to be sent to Control Unit
    t1 += 100;
  }

 
  ardu_test = bitRead (ardu_cmd, 1); //reading of "test" command status coming from Control Unit
   
  /*Leds alternate blinking if Control Unit sends a "test" command */
  if (osc)
  {
    if (ardu_test) {
      digitalWrite(10, HIGH);
      digitalWrite(9, LOW);
    }
  }
  else
  {
    if (ardu_test) {
      digitalWrite(10, LOW);
      digitalWrite(9, HIGH);
    }

  }

 /*stops balancing in case of cell voltage decreases below 3200 mV, by MOS-p channel */
  if (volt > 3200) {digitalWrite(0, LOW);}
     else  {digitalWrite(0, HIGH);}
    

  check = Life (ardu_life, 1000, life_mem, t_life); //check of sign of life value coming from Control Unit
  net_fault = TON (check, 20000, net_elapsed, net_count); //this variable is set after 20 seconds of communication loss 
  ardu_rst = bitRead (ardu_cmd, 2); //reading of "reset" command status coming from Control Unit

  /*in case of communication loss OR reset command from Control Unit, Attiny is Reset*/
  if ((net_fault)||(ardu_rst)) {
    Riavvia();
  }

  
  if (!ardu_test) { // leds management in normal condition without "test" command from Control Unit

    /*D1 led blinks every 1000msec (check function time) if communication with Control Unit is ok*/
    if (check) {
      digitalWrite(9, HIGH);
    }
    else {
      digitalWrite(9, LOW);
    }


    /*D2 led blinks every 600msec if Sketch is executed*/
    if (millis() - t0 >= 600)
    {
      digitalWrite(10, HIGH);
      t0 += 600;
    }
    else {
      digitalWrite(10, LOW);
    }
  }


   /*Voltage value adjustment by push buttons.*/
  
  comp_enable = bitRead (ardu_cmd, 3);
  
  if (comp_enable && u_n) {
    gain_offset++;
    EEPROM.put (2,gain_offset);
  }

  if (comp_enable && da_n) {
    gain_offset--;
    EEPROM.put (2,gain_offset);
  }

  /*Voltage value calculation */
  float cell_val = float (val);
  float cell_gain = (1000 - ((cell_val-3000)*0.0067)) + gain_offset;
  float cell_calc = (cell_val * cell_gain) / 1000;
  vx = long (cell_calc);

/*balancing oscillator*/
  time1_q = TON (!time2_q, 5000, elapsed_time1, count_time1);
  time2_q = TON (time1_q, 50, elapsed_time2, count_time2);

  ardu_bleed = bitRead (ardu_cmd, 0); //reading of "bleeding" command status coming from Control Unit
  
  time3_q = TON (!bleed_on, 25, elapsed_time3, count_time3);
  
  if (ardu_bleed && !time1_q){
    tiny_bal = ardu_bal;
    bleed_on = true;
    } //in case of "bleeding" command, set balancing value according to parameter coming from Control Unit
  else {
          tiny_bal = 0; //set balancing value to zero if no command of bleeding arrives
          bleed_on = false;
          if (time3_q) {
          volt = vx; //update voltage value for LCU, only when balancing is off for at least 25 msec
          }
    } 
  analogWrite(8, tiny_bal); //write PWM balancing value to Mosfet 

    
 
  temp1_mv = map(temp1_filtered, 0, 1023, 0, volt);//temperature mV signal calculation according to ADC supply voltage
  temp1 = map (temp1_mv, 100, 1750, 0, 255); //temperature converted in a byte value

  temp2_mv = map(temp2_filtered, 0, 1023, 0, volt);
  temp2 = map (temp2_mv, 100, 1750, 0, 255);

}



/*Program Mode to set the cell module I2C address*/
void program() {

  if (prog_p) {// executed one time at the start of program mode 
    sample = 300;// sample time of leds blinking management (in msec)
   
    /*decrement of tens and units numbers*/
    u_number--;
    da_number--;
    u_led_elapsed = 0;
    da_led_elapsed = 0;
    digitalWrite(9, HIGH); // both leds on to show the end of program mode
    digitalWrite(10, HIGH);
    delay(3000); //three seconds of freezing before starting the program mode
  }
  prog = !both_p; //in case of pressing of both buttons for 3 seconds, system returnes to normal mode
  
  if (u_n) { //increment of units value after SW1 button release
    u_number++;
  }
  if (da_n) { //increment of tens value after SW2 button release
    da_number++;
  }
  if (u_number > 9) { //restart of units value
    u_number = 0;
  }
  if (da_number > 9) { //restart of tens value
    da_number = 0;
  }
  new_address = (da_number * 10) + u_number; //new address number calculation
  
  /*preset values of leds blink mangement */
  u_led_preset = u_number + 2;
  da_led_preset = da_number + 2;
  osc_n = NegTrig(osc, osc_mem);

  if (millis() - t >= sample) //oscillator for blinking
  {
    osc = !osc;
    t += sample;

  }



  if (osc)
  {
    if ((u_led_elapsed >= 1) && (u_led_elapsed <= u_number)) { //blinking of Units led to show the set value
      digitalWrite(10, HIGH);
    }
    else  {
      digitalWrite(10, LOW);
    }

    if ((da_led_elapsed >= 1) && (da_led_elapsed <= da_number)) { //blinking of Tens led to show the set value
      digitalWrite(9, HIGH);
    }
    else  {
      digitalWrite(9, LOW);
    }

  }
  else
  {
    digitalWrite(10, LOW);
    digitalWrite(9, LOW);
  }

  if (osc_n) //led blinking counters increment or reset every negative edge of the oscillator
  {
    u_led_elapsed++;
    if (u_led_elapsed > u_led_preset) {
      u_led_elapsed = 0;
    }
    da_led_elapsed++;
    if (da_led_elapsed > da_led_preset) {
      da_led_elapsed = 0;
    }
  }

}

/*I2C bytes transmission according to Control Unit request: tot.5 bytes*/
void requestEvent() {
  byte valLow = volt & 0xff;
  byte valHigh = (volt >> 8);
  TinyWireS.send(valHigh);
  TinyWireS.send(valLow);
  TinyWireS.send(temp1);
  TinyWireS.send(temp2);
  TinyWireS.send(tiny_life);
}

/*I2C bytes reception according to Control Unit transmission: tot.3 bytes*/
void receiveEvent() {
  ardu_bal = TinyWireS.receive();
  ardu_life = TinyWireS.receive();
  ardu_cmd = TinyWireS.receive();
}

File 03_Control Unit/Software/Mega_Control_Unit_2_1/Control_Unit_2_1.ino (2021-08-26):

/*
  Control_Unit
  
  Master Unit of Green BMS project.
  Control Unit is based on Arduino Mega.
  Control Unit functions are:
    - To communicate by I2c with all the cell modules of the battery pack
    - To receive from cell modules the values of: cell voltage, cell pole temperature, balancing resistor temperature for battery pack management system
    - To send to cell modules the balancing command
    - To perform the following safety functions by relays:
              - Charge ok: open two relays contact when just one cell of the pack reach the high value or I2C communication with Cell modules is loss
              - Discharge ok: open a relay contact when just one cell of the pack goes down the minimum value or I2C communication with Cell modules is loss
              - Alarm led: close a contact to supply a led in case of alarm
              - Balancing: close a contact when just one cell of the pack is balancing: this information can be used to reduce the charging current 
              - System OK: close a contact when Control Unit is working.
   - To communicate with an Android device by a Bluetooth module. Android device is the human machine interface from wich is possible to check the BMS status and set parameters.
    
 
 Versions:

  - Ver. 3.s.2.01 date 26/08/2021 created by Sergio Ghirardelli (first release)
   
*/

#include <Wire.h>
#include "functions_4.h"
#include <EEPROM.h>
#include <SoftwareSerial.h>
#include <avr/wdt.h> 

struct cell_str {
  
  /*bytes coming from cell modules*/
  byte valHigh;
  byte valLow;
  byte temp1;
  byte temp2;
  byte tinyLife;
 
  /*bytes sent to cell modules*/
  byte bleed_cmd;
  byte arduLife;
  byte cmd;
 
  /*voltage calculation variables*/
  int millivolt;  
  float volt;
  

  /*variables used to "veryhigh" value check */
  unsigned long elapsed_veryhigh;
  unsigned long count_veryhigh;
  bool mem_veryhigh;
  bool veryhigh;
  
  /*variables used to "high" value check */
  unsigned long elapsed_high;
  unsigned long count_high;
  bool mem_high;
  bool high;

  /*variables used to "bal" value check */
  unsigned long elapsed_bal;
  unsigned long count_bal;
  bool mem_bal;
  bool bal;

  /*variables used to "low" value check */
  unsigned long elapsed_low;
  unsigned long count_low; 
  bool mem_low;
  bool low;

  /*variables used to "err" value check */
  bool in_err;
  unsigned long elapsed_err;
  unsigned long count_err;
  bool err;
  unsigned long high_err_elapsed;
  unsigned long high_err_count;
  bool high_err;
  bool high_err_mem;

  bool normal; //the cell has a value in the normal range

  /*variables used to check communication with cell module*/
  bool check;
  bool net_fault;
  byte life_mem;
  unsigned long t_life;
  unsigned long net_elapsed;
  unsigned long net_count;

  /*variables used for cell pole temperature management*/
  int pole_temp;
  unsigned long elapsed_pole_t;
  unsigned long count_pole_t;
  bool mem_pole_t;
  bool high_pole_temp;

  /*variables used for balance resistors temperature management*/
  int bal_temp;
  unsigned long elapsed_bal_t;
  unsigned long count_bal_t;
  bool mem_bal_t;
  bool high_bal_temp;
  bool bal_enable;

  /*test bit to cell module */
  bool ardu_test;
  
};

struct cell_str cell[41];

/*variables used for sampling each cell module data exchange  */
int n; //number of cells
int i; //address incremented every cycle

/*variables used to find the highest and the lowest cells voltage*/
int cell_max_mem;
int cell_min_mem;
int cell_max;
int cell_min;

/*variables used to calculate the total battery pack voltage */
float pack_voltage;
float pack_voltage_mem;

/*variable used to calculate if just one cell is in error status*/
bool just_err; 
bool just_err_mem;

/*variable used to calculate if just one cell is in high status*/
bool just_high; 
bool just_high_mem;

/*variable used to calculate if just one cell is in very high status*/
bool just_veryhigh; 
bool just_veryhigh_mem;

/*variable used to calculate if just one cell is in bal status*/
bool just_bal; 
bool just_bal_mem;

/*variable used to calculate if just one cell is in low status*/
bool just_low; 
bool just_low_mem;

/*variable used to calculate if just one cell pole temperature is in high status*/
bool just_pole; 
bool just_pole_mem;

/*variable used to calculate if just one cell balancing resistor is in high status*/
bool just_bal_t; 
bool just_bal_t_mem;

/*variable used to calculate if just one cell is balancing*/
bool just_bleed;
bool just_bleed_mem;

/*variable used to calculate if all the cells reach the bal status*/
bool all_bal; 
bool all_bal_mem;

/*variable used for current sensor*/
int cur_filter_mem[10];
int cur_filter_index;
long current_mA;
float current_A;
long cur_after_offset;
bool standby;
bool charge_fdbk;
bool discharge_fdbk;
float load;
int current_filtered;
int current_channel;
long cur_sign;
long current_map;
bool current_error;

/*variable used for SOC calculation*/
float soc_mAh; 
float soc_mAh_max;
unsigned long h;
int soc_perc;
int soc_perc_old;

/*variable used for oscillators*/
unsigned long t_500;
bool osc_500;
unsigned long t_800;
bool osc_800;
unsigned long t_2000;
bool osc_2000;
unsigned long t_10000;
bool osc_10000;
unsigned long t_30000;
bool osc_30000;

/*variables for store index*/
unsigned long t_index;
int status_index;
float soc_mah_stored;
int soc_mem_address;
bool pack_ch_stored;
int ch_mem_address;
bool pack_bal_stored;
int bal_mem_address;

/*parameters*/
int first_code; // code written in case of first use
int password; // password to connect by bluetooth app

unsigned long set_status_time; //  Delay time for each status settings

int set_veryhigh; //  Very High Voltage threshold (set): alarm
int set_veryhigh_hys; //  Very High Voltage Reset (when voltage decreases below this value)
int set_high; //  High Voltage threshold : not alarm but stop charging
int set_high_hys; // High Voltage Reset (when voltage decreases below this value)
int set_bal; // Balance Voltage threshold (set) : start of balancing. Battery pack is considered charged when all the cells reach this value
int set_bal_hys; // Balance Voltage Reset (when voltage decreases below this value)
int set_low; // Low Voltage threshold (set): alarm and stop discharging
int set_low_hys; // Low Voltage Reset (when voltage increases above this value)

unsigned long set_timeout; // Cell communication timeout error
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

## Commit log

2021-08-26 First release
    [ADUM1250.step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]
2023-12-08 Update README.md
    added buy me a coffee button
